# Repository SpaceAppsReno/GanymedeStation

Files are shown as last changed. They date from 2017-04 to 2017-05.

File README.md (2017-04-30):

# GanymedeStation
Garden control system

<p>
The garden will contain a series of Pods to monitor conditions.
Pods will include a moisture sensor, thermistor, and radio transmitter.
Pods will be controlled by an Arduino microcontroller.
</p>

Each pod will provide the following data:
* id
* moisture
* temperature
* light
* voltage (batter)
This data will be transmitted to a nearby base station.

<p>
There will be a base station near the garden to receive radio transmissions from the pods.
Each base station will have a flow meter, water controller, radio receiver, and a connection to the internet.
Data from the pods is aggregated by the base station, and posted to the Ganymede server.
</p>

<p>
The Ganymede server will receive and store data from the base station(s).
The data may be accessed through a REST API by clients.
</p>
<p>PUT /api/[BaseStationId]         - Sets the current battery level and flow value</p>
    <p>
    {
      "name":"MyBaseStation",
      "flow":"9000",
      "voltage":"3.3",
      "valves":["valve1","valve2"]
    }
    </p>
<p>PUT /[BaseStationId]/[PodId] - Sets the current values of the sensors for the pod</p>
    <p>
    {
      "name":"MyPod1",
      "temperature":"16",
      "moisture":"255",
      "light":"50",
      "voltage":"3.3"
    }
    </p>
<p>GET  /                        - Retrieves a list of metadata for all base stations</p>
    <p>
    [
      {"name":"MyBaseStation"},
      {"name":"MyBaseStation2"}
    ]
    </p>
<p>GET  /[BaseStationId]         - Retrieves battery level and metadata for all pods associated with the base station</p>
    <p>
    {
      "_id":"59061e3e8f9ad902fdac9d17",
      "modified":"2017-04-30T17:26:22.255Z",
      "name":"MyBaseStation",
      "flow":9000,
      "voltage":3.3,
      "created":"2017-04-30T17:26:22.254Z",
      "__v":1,
      "valves":["valve1","valve2"],
      "pods":["MyPod1"]
    }
    </p>
<p>GET  /[BaseStationId]/[PodId] - Retrieves current sensor data for the specified pod</p>
    <p>
    {
     "_id":"59061e568f9ad902fdac9d18",
     "light":50,
     "moisture":255,
     "temperature":16,
     "voltage":3.3,
     "name":"MyPod1",
     "baseStation":"MyBaseStation",
     "created":"2017-04-30T17:26:46.731Z",
     "__v":0
    }
    </p>
<p>
A desktop version of the client will be created in WPF for displaying and controlling each base station.
</p>

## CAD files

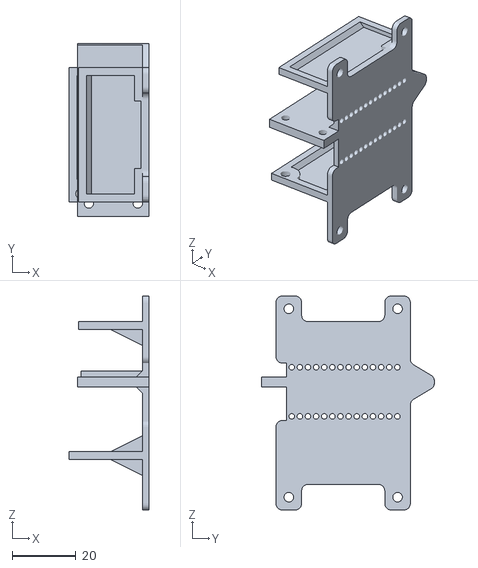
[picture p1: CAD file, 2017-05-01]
CAD/Node Components/print/core printed v2.stl
25.0 x 54.0 x 66.9

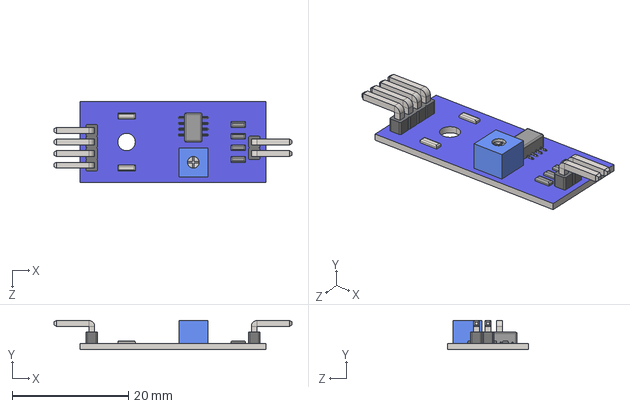
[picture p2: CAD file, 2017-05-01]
CAD/Node Components/soil sensor.STEP
41.0 x 5.00 x 14.0 mm

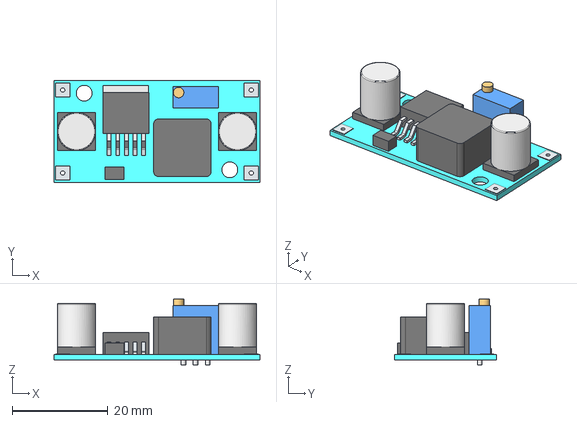
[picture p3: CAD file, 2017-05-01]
CAD/Node Components/Step Down voltage regulator LM2596.stp
43.0 x 21.2 x 13.7 mm

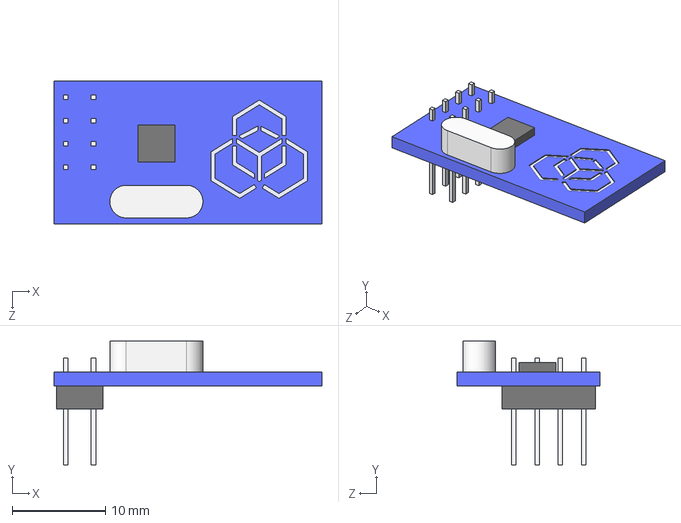
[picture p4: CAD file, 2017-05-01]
CAD/Node Components/NRF24L01+.STEP
28.8 x 13.3 x 15.4 mm

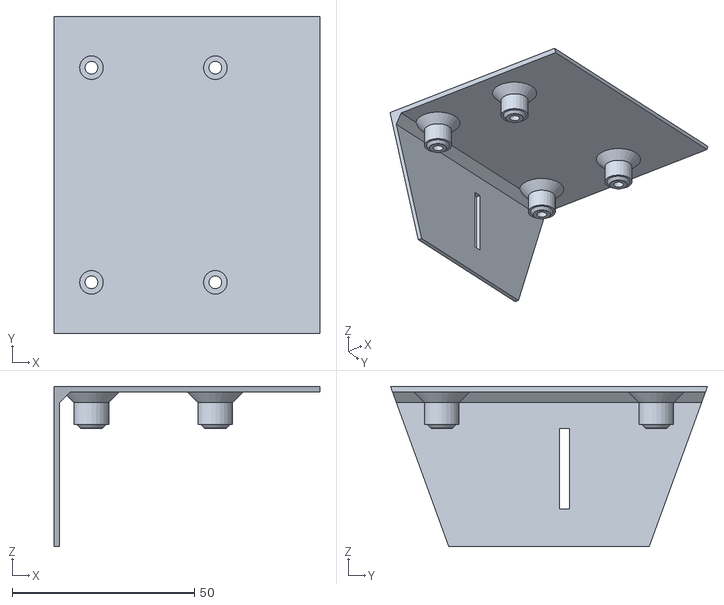
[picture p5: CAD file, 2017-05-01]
CAD/Node Components/print/Case 2.stl
73.0 x 87.0 x 44.0

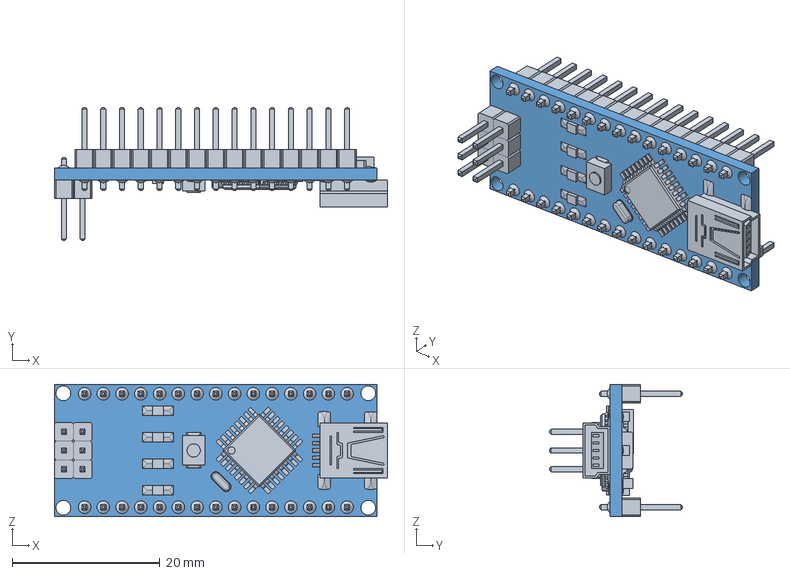
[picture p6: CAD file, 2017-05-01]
CAD/Node Components/NanoV3 v4.step
45.1 x 18.0 x 17.9 mm
switch
Led x 3
Led (1)
Pin x 21
chip1
USB
Crystal
Pin (1) x 15
Res x 5
cap x 2
Chip
respack x 2
diode
vreg

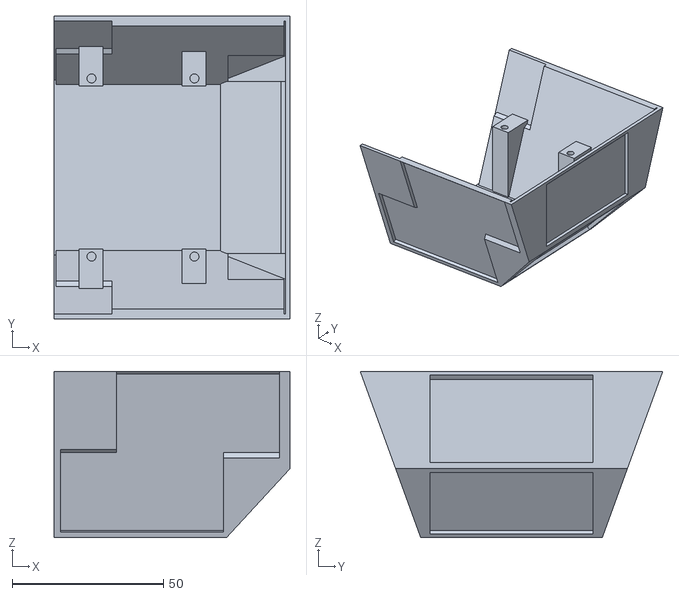
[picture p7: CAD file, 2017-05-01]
CAD/Node Components/print/Case 1.stl
78.0 x 100.0 x 55.0

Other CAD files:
CAD/Node Components/print/core printed.stl
CAD/Ganymede Farm Controller Assembly.iam
CAD/Hub Components/Ganymead Hub.iam
CAD/Node Components/Case 1.ipt
CAD/Node Components/Case 2.ipt
CAD/Node Components/Ganymede Node.iam
CAD/Node Components/NRF24L01+.ipt
CAD/Node Components/NanoV3 v4.ipt
CAD/Node Components/OldVersions/Case 1.0009.ipt
CAD/Node Components/OldVersions/Ganymede Node.0015.iam
CAD/Node Components/OldVersions/core printed.0010.ipt
CAD/Node Components/Step Down voltage regulator LM2596.ipt
CAD/Node Components/battery.ipt
CAD/Node Components/core printed.ipt
CAD/Node Components/moist probe.ipt
CAD/Node Components/soil sensor.ipt
CAD/Node Components/solar cell 26x52.ipt
CAD/OldVersions/Ganymede Farm Controller Assembly.0001.iam

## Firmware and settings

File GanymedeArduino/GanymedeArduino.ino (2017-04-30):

#include <SPI.h>
#include "RF24.h"

/****************** Radio Config ***************************/
/***      Set this radio as radio number 0 or 1         ***/
bool radioNumber = 0;
/* Hardware configuration: Set up nRF24L01 radio on SPI bus plus pins 9 & 10 */
RF24 radio(9,10);

byte addresses[][6] = {"1Node","2Node"};
/**********************************************************/

// pin assignments
#define MOISTURE_SENSOR A6
#define LIGHT_SENSOR    A1
#define TEMP_SENSOR     A2

typedef struct{
  int16_t moisture;
  int16_t light;
  int16_t temp;
  int16_t volts;
}
s_data;

s_data sensorData;

void setup() {
   // start serial for debug output
   Serial.begin(9600);
   
   
   Serial.println(F("Ganymede Station Sensor Node"));
   
   
   // radio setup
   radio.begin();
   // Set the PA Level low to prevent power supply related issues due to
   // likelihood of close proximity of the devices. RF24_PA_MAX is default.
   //radio.setPALevel(RF24_PA_LOW);
   
   // Open a writing and reading pipe on each radio, with opposite addresses
   radio.openWritingPipe(addresses[0]);
   radio.openReadingPipe(1,addresses[1]);
}

void loop() {
   sensorData.moisture = getMoistureReading();
   sensorData.light = getLightReading();
   sensorData.temp = getTempReading();
   sensorData.volts = getVccReading();

   Serial.println(F("Now sending sensor data"));
   if (!radio.write( &sensorData, sizeof(sensorData) )){
       Serial.println(F("failed to send sensor data\n"));
   }
   delay(3000);
}


int16_t getMoistureReading()
{
   int moistValue = analogRead(MOISTURE_SENSOR);
   
   Serial.print("Moisture: ");
   Serial.println(moistValue);
   
   return moistValue;
}


int16_t getLightReading()
{
  int lightValue = analogRead(LIGHT_SENSOR);
  Serial.print("Light: ");
  Serial.println(lightValue);

  return lightValue;
}

int16_t getTempReading()
{
   const int SERIESRESISTOR = 10000;
   const int NUMSAMPLES = 5;
   int samples[NUMSAMPLES];
   uint8_t i;
   float average;
 
   // take N samples in a row, with a slight delay
   for (i=0; i< NUMSAMPLES; i++) {
      samples[i] = analogRead(TEMP_SENSOR);
      delay(10);
   }

   // average all the samples out
   average = 0;
   for (i=0; i< NUMSAMPLES; i++) {
      average += samples[i];
   }
   average /= NUMSAMPLES;
   
   // convert the value to resistance
   average = 1023 / average - 1;
   average = SERIESRESISTOR / average;
   Serial.print("Thermistor resistance: ");
   Serial.println(average);

   return resistanceToCelsius(average);
}


// this code from: https://learn.adafruit.com/thermistor/using-a-thermistor
// thanks lady ada!
int16_t resistanceToCelsius(float resistance)
{
   // resistance at 25 degrees C
   const int THERMISTOR_NOMINAL = 10000;
   // temp. for nominal resistance (almost always 25 C)
   const int TEMPERATURE_NOMINAL = 26;
   // The beta coefficient of the thermistor (usually 3000-4000)
   const int B_COEFFICIENT = 3950; //3950?

   float steinhart;
   steinhart = resistance / THERMISTOR_NOMINAL;     // (R/Ro)
   steinhart = log(steinhart);                  // ln(R/Ro)
   steinhart /= B_COEFFICIENT;                   // 1/B * ln(R/Ro)
   steinhart += 1.0 / (TEMPERATURE_NOMINAL + 273.15); // + (1/To)
   steinhart = 1.0 / steinhart;                 // Invert
   steinhart -= 273.15;                         // convert to C
   
   Serial.print("Temperature: "); 
   Serial.print(steinhart);
   Serial.println(" *C");

   return (int16_t)steinhart;
}

// this code from: https://forum.arduino.cc/index.php?topic=356752.0
// thanks johnwasser!
int16_t getVccReading() {
  long result;
  // Read 1.1V reference against AVcc
  ADMUX = _BV(REFS0) | _BV(MUX3) | _BV(MUX2) | _BV(MUX1);
  delay(2); // Wait for Vref to settle
  ADCSRA |= _BV(ADSC); // Convert
  while (bit_is_set(ADCSRA,ADSC));
  result = ADCL;
  result |= ADCH<<8;
  result = 1126400L / result; // Back-calculate AVcc in mV

   Serial.print("Vcc: ");
   Serial.println(result);
   
  
  return (int16_t)result;
}

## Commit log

2017-04-30 calibration, update interval
    calibrate temp, change moisture sensor pin, changed update interval to
    3 seconds
2017-04-30 increase Tx power, change pin
    change moisture pin, increase Tx power to max
2017-04-30 change pin AGAIN, un-fudge temp
2017-04-30 Update to UI to call timer to update realtime value every 5 seconds
2017-05-01 Added CAD files in Autodesk inventor format
    [Case 1.0009.ipt, Case 1.ipt, Case 1.stl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]
